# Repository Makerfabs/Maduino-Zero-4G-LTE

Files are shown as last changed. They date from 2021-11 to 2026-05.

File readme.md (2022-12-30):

# Maduino Zero 4G LTE

```c++
/*
Version:		V1.1
Author:			Vincent
Create Date:	2021/11/5
Note:
	2022/12/30	V1.1:	Change Wiki link.
*/
```
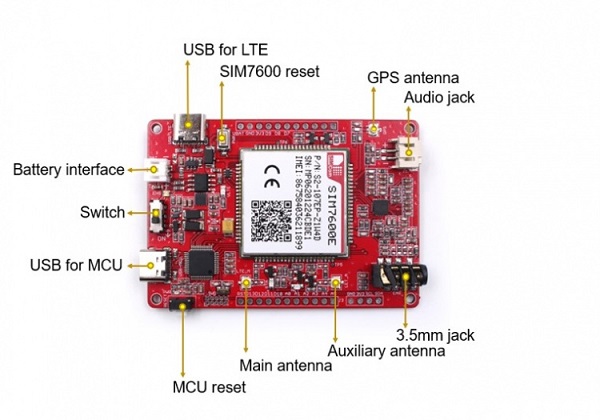
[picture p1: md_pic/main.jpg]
main


[toc]

# Makerfabs

[Makerfabs home page](https://www.makerfabs.com/)

[Makerfabs Wiki](https://wiki.makerfabs.com/)

# Maduino Zero 4G LTE
## Intruduce

Product Link ：[Maduino Zero 4G LTE(SIM7600X)](https://www.makerfabs.com/maduino-zero-4g-lte-sim7600.html) 

Wiki Link : [Maduino Zero 4G LTE](http://wiki.makerfabs.com/Maduino_Zero_4G_LTE.html) 

Maduino Zero 4G LTE integrated two types of the 4G LTE CAT4 module SIM7600A-H or SIM7600E-H, SIM7600A-H/SIM7600E-H is a complete multi-band LTE-FDD/LTE-TDD/HSPA+/UMTS/EDGE/GPRS/GSM module solution in LCC type which supports LTE CAT4 up to 150Mbps for downlink and 50Mbps for uplink data transfer, much faster and popular than 2G/3G.

## Module Type

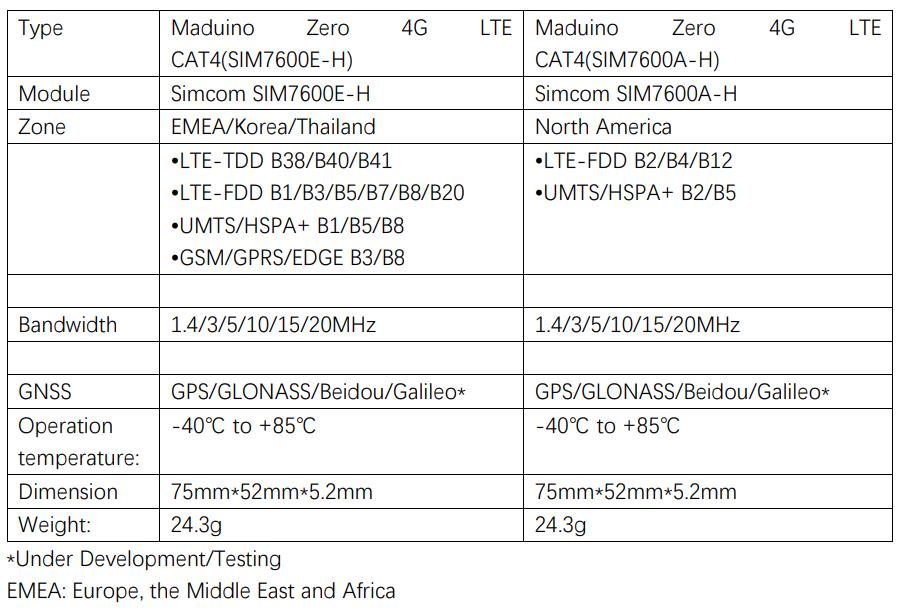
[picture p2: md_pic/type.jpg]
type


## Feature

- Supports dial-up, phone, SMS, TCP, UDP, DTMF, HTTP, FTP, and so on
- Dual USB Type C port
- Control Via AT Commands
- Board USB supply voltage range: 4.8~5.5V, 5.0V Typical
- Board Battery supply voltage range: 3.4~4.2V, 3.7V Typical
- 3GPP E-UTRA Release 11
- Onboard charger, up to 1A charge current
- Overcharge protection(OCP), 4.3V
- Over-discharge protection(ODP), 2.5V
- Power Manager, the board can be supplied by USB or battery.
- IPEX Antenna, GSM/UMTS/LTE main antenna. UMTS/LTE auxiliary antenna. GNSS antenna
- SMS support
- Audio support
- On boarder controller: ATSAMD21G18A
- Audio chip: NAU8810
- Level Shifter: TXS0108E

### Front:

front

### Back:
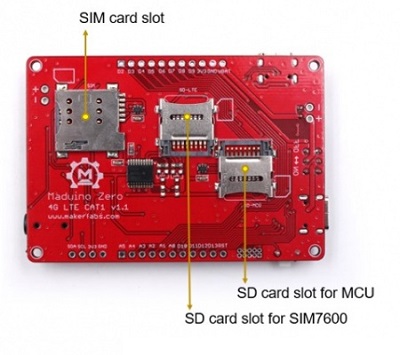
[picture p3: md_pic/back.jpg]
back


### Frequency bands

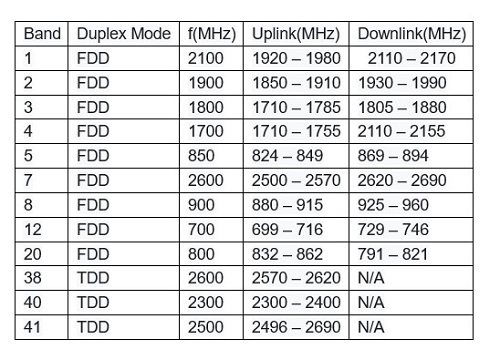
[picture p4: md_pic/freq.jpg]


### Transfer Speed

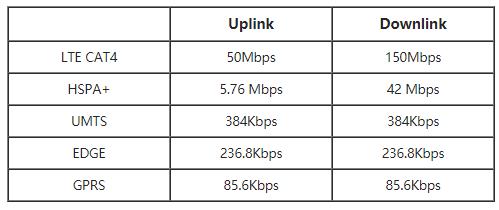
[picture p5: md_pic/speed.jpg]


# Usage （Arduino）

## Equipment list

- Maduino Zero 4G (With GPS antenna and two 4G-GSM antennas)
- SIM card 

*Ensure that SIM7600 requirements are met and that the system can communicate with local carriers. We used China Mobile's 4G card for testing.*

## Compiler Options

**If you have any questions，such as how to install the development board, how to download the code, how to install the library. Please refer to :[Makerfabs_FAQ](https://github.com/Makerfabs/Makerfabs_FAQ)**

- Connect all antennas
- Insert a SIM card
- Connect **USB for MCU** to PC

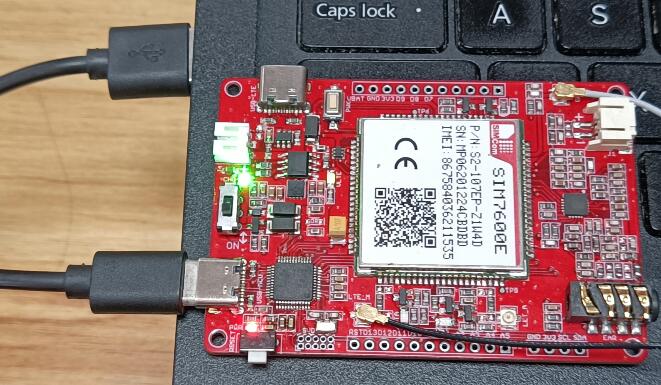
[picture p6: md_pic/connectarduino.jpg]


- Upload codes, select "Arduino Zero" and "Native USB"

## Example List

### AT_command_demo

Input AT commands via serial monitor to learn how to use 4G module. This version is modify for SIM7600.

If define MODE_1A, when "1A" or "1A" is entered, 0x1A is sent to the module.

When sending SNS information, you need to send 0x1A to end the input.

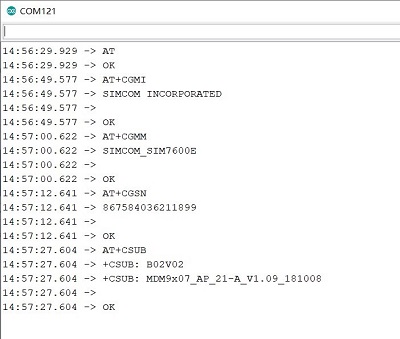
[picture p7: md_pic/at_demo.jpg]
at_demo


### 4G_HTTP_DHT11_V1.0

Air temperature and humidity information detected by the DHT11 module is sent to ThingSpeak using a cellular network.

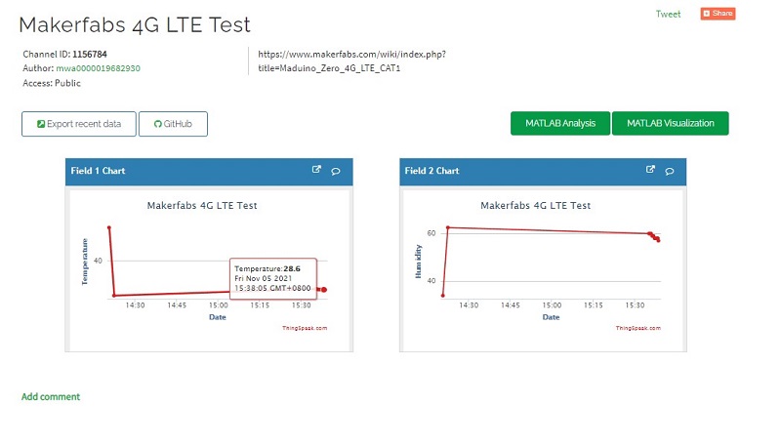
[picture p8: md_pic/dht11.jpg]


## AT Command Explain

###  AT commands test

Refer to the official AT manual of SIM7600 for detailed return values.

```c++
    AT+CGMI    // Request manufacturer identification
    AT+CGMM    // Request model identification
    AT+CGSN    // Request product serial number identification
    AT+CSUB    // Request the module version and chip
    AT+CPIN?     // Request the state of the SIM card
    AT+CICCID    // Read ICCID from SIM card
    AT+CNUM      // Request the subscriber number
    AT+CNMP?     // Preferred mode selection
    AT+COPS?     // Check the current network operator
```

### Get the GNSS location

GPS signal acquisition speed depends on signal strength, please wait patiently in an open place.

```c++
    AT+CGPS=1      // Start GPS session 
    AT+CGPSINFO    // Get GPS fixed position information
    AT+CGPS=0      // Stop GPS session
```

### Send and receive SMS

Please consult the operator for the phone number of the SMS center. The number "+8613800755500" in Shenzhen was used in the test. 

```c++
    AT+CSCA="XXXXXX"       // Set the SMS service centre address
    AT+CMGF=1              // Select SMS message format
    AT+CMGS="xxxxxx"       // Send message to "xxxxxx"(the receiver number).
```

"AT+CMGS" sets the phone number of the receiver and returns ' >' . Send desired content, such as "Send Massage Test!".After editing a short message, send it in hexadecimal format 1A Send a message.

*The Arduino IDE cannot send hexadecimal,  you can use other software. In the example code, entering 1A or 1A will send 0x1A to the module.*

# Usage （Raspberry Pi）

## Equipment list

- Maduino Zero 4G (With GPS antenna and two 4G-GSM antennas)
- SIM card 

*Ensure that SIM7600 requirements are met and that the system can communicate with local carriers. We used China Mobile's 4G card for testing.*

- Connect all antennas
- Insert a SIM card
- Connect **USB for MCU** to Raspberry Pi USB

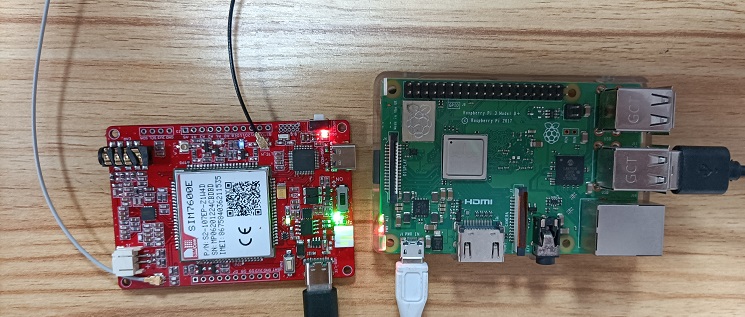
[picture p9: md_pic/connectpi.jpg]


## Used as a 4G network adapter

### Hardware Check

- Log in to the root account and perform all subsequent operations as the root account.

```shell
sudo su
```

- Install the Minicom serial port tool.

```shell
apt-get install minicom
```

- To view the serial port device, AT command serial port: "/dev/ttyUSB2"

```shell
ls /dev/ttyUSB*
```

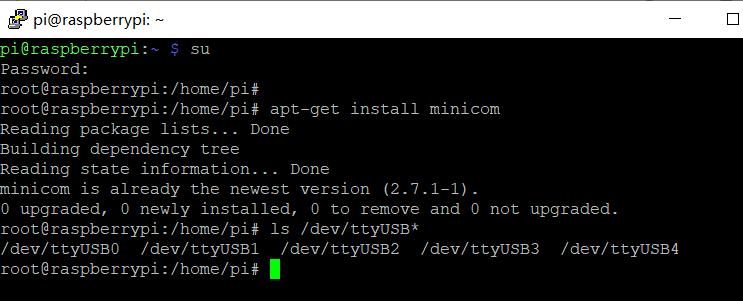
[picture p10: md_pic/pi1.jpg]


- Open the serial port with Minicom

```shell
minicom -D /dev/ttyUSB2
```

- Enter the AT command in minicom

```shell
# Forcibly set the Internet access to 4G
AT+CNMP=38
# Querying network Quality
AT+CSQ
# Query the network registry
AT+CREG?
# Querying Network Carrier Information
AT+COPS?
# Querying network band
AT+CPSI?
```

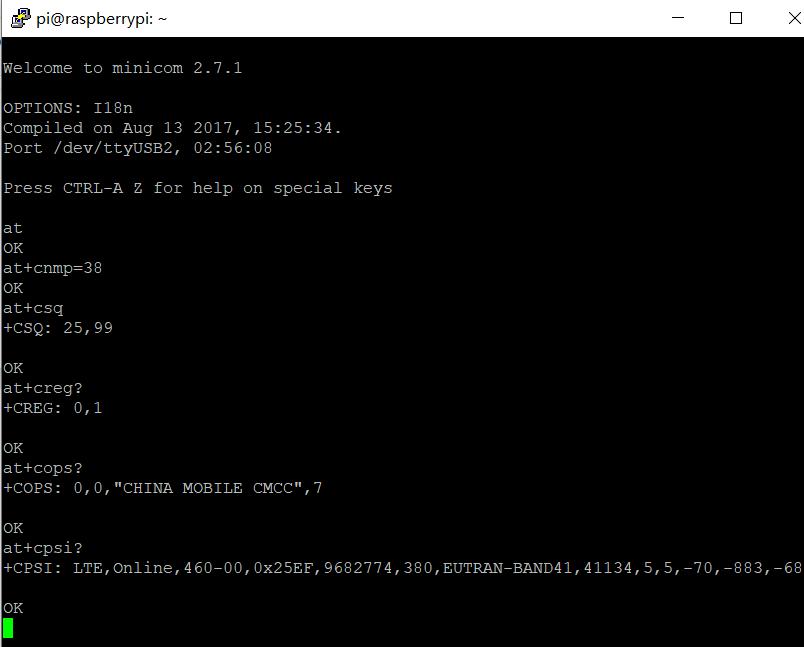
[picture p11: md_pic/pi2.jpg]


- \- Press Ctrl + A, then X to exit Minicom

At this point, the hardware and network connections between SIM7600CE and Raspberry Pi are normal. This case uses the 4G card of China Mobile. If you cannot use the other areas, please ask SIMCOM. 

### Driver Install

By default, Raspbian is installed with Qualcomm driver files for the wwan0 network port. For Raspberry Pi, you need to uninstall the driver first (otherwise it will conflict with the new driver), and then install the Simcom's driver for wwan0.

- Check system drivers

```shell
lsmod
```

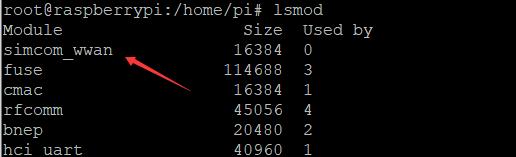
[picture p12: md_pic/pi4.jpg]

- Uninstalling an existing driver

```shell
rmmod qmi_wwan
```

- Install the raspberry PI kernel header file
```shell
apt install raspberrypi-kernel-headers
```
- Download the official driver program provided by SIMCOM
```shell
wget https://www.waveshare.net/w/upload/0/00/SIM7600_NDIS.7z
```
- Install the decompression tool and decompress it
```shell
apt-get install p7zip-full
7z x SIM7600_NDIS.7z -r -o ./SIM7600_NDIS
```
- Go to the driver folder and compile

```shell
cd SIM7600_NDIS
make clean
make
ls
```

- Install the driver module file

```shell
insmod simcom_wwan.ko
```

- Check whether the installation is successful
```shell
lsmod
```



### Assign IP addresses

- In this case, the wwan0 network port is displayed

```shell
ifconfig -a
```
- However, no IP address is assigned to the network port. To assign an IP address, enable the network port first

```shell
ifconfig wwan0 up
```
- Then, through Minicom, enter the AT command to start dialing

```shell
minicom -D /dev/ttyUSB2
AT$QCRMCALL=1,1
```
- Finally, exit Minicom and assign IP

```shell
apt-get install udhcpc
udhcpc -i wwan0
```
- Run the Ping command to check whether the network adapter is connected

```shell
ping -I wwan0 www.baidu.com
```

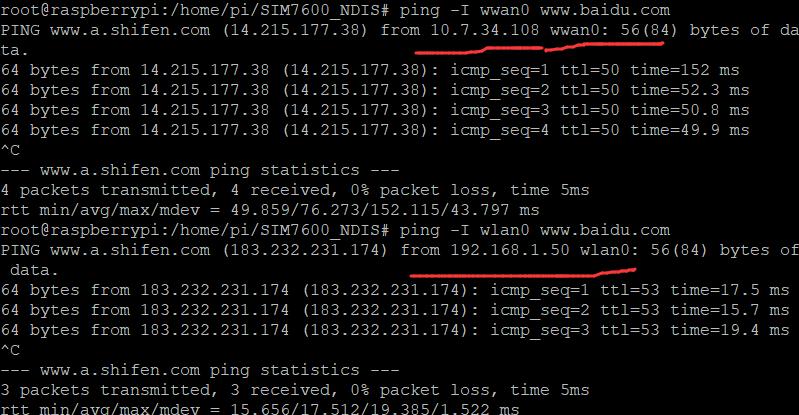
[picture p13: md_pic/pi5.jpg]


# Usage （Windows）

- Connect one end of USB cable to USB interface of PC and the other end to USB_LTE interface of Maduino Zero 4G LTE.

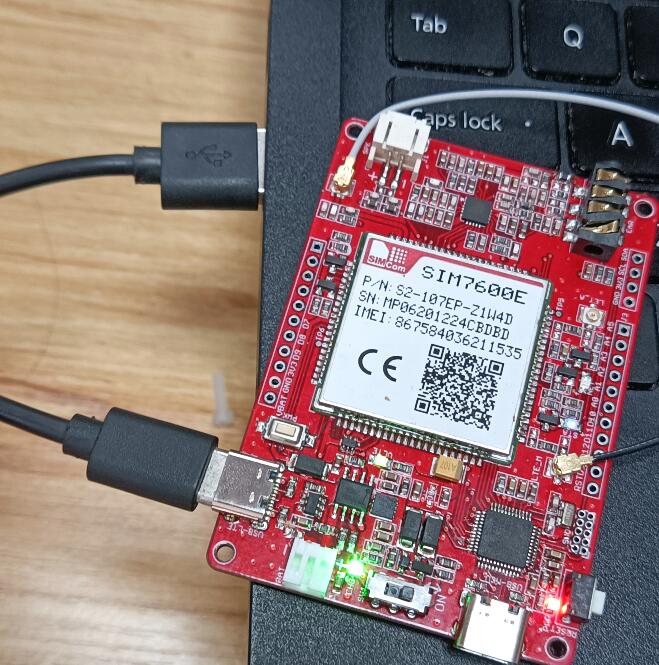
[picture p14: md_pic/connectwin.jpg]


- Open the device manager and you can see these COM ports.



- If the COM port is identified in the figure above, but an exclamation mark appears, it indicates that the driver is not installed.
- Driver is in "Maduino-Zero-4G-LTE\win_driver\SIM7600X-Driver.7z"
- Open Device Manager - > Other equipment - >“SimTech,Incorporated”- >  Update the driver - > Browse my computer to find driver files - > Select a path for saving the driver file based on the system- >The installation is complete.

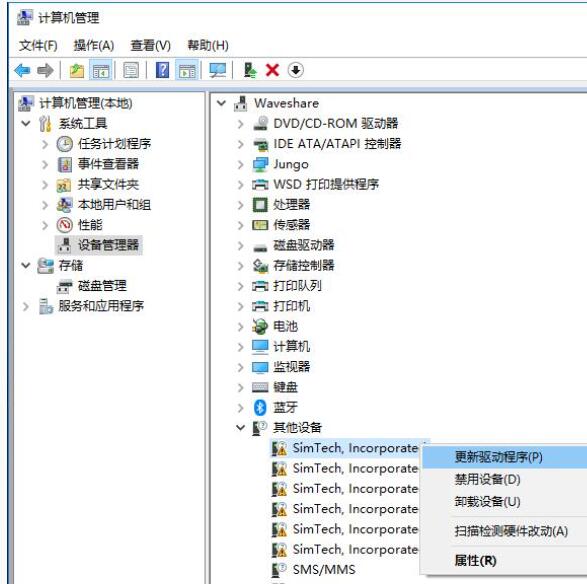
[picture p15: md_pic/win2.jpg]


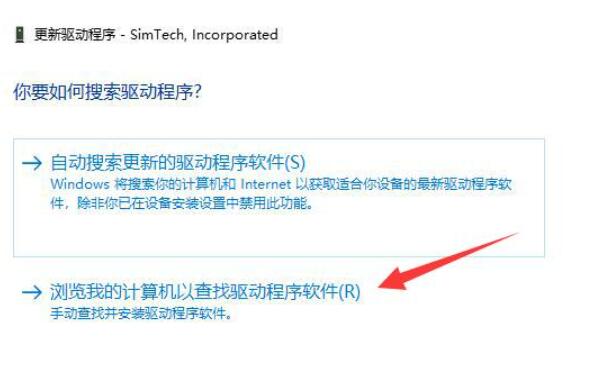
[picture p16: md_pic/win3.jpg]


- Install the driver for each exclamation point
- The network icon will then appear as a cellular network.

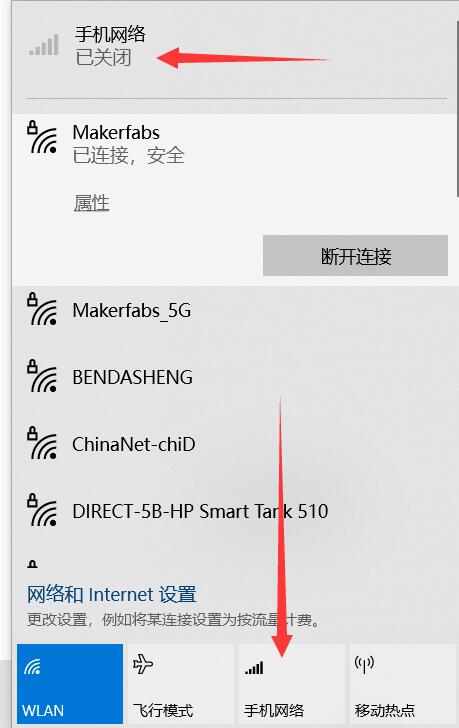
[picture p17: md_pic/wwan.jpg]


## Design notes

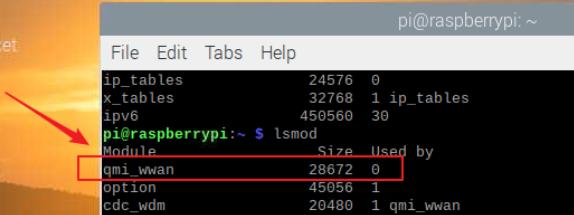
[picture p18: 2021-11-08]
md_pic/pi3.jpg

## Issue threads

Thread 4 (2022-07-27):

How to connect another serial device to board

keithfraley, 2022-07-27:
My understanding is that this board has two serial ports, one for serialUSB and one for serial1 used to communicate to the Modem.

I have another external serial device that I need to connect to the board.  Can you tell me how best to do this, specifically what digital port is configured to recieve data from a serial device via UART?

Thanks

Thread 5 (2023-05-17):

Is there a way to hard reset the board (No device found on COM5)

norcino, 2023-05-17:
When I try to upload a sketch (any, even empty), Arduino IDE gets stuck in Uploading....

Sometimes, but generally resetting the board with the button I get the expected.

"No device found on COM5"
"Failed upload: uploading error: exit status 1"

Is there anything I can do? I barely used the board to try commands and started writing a sketch.

norcino, 2023-07-22:
Plug the device and turn it on.
Touch the press the MCU reset button twice (quicly).
Wait a few seconds and when the device will be ready in Arduino, proceed with the upload.

Closed 2023-07-22.

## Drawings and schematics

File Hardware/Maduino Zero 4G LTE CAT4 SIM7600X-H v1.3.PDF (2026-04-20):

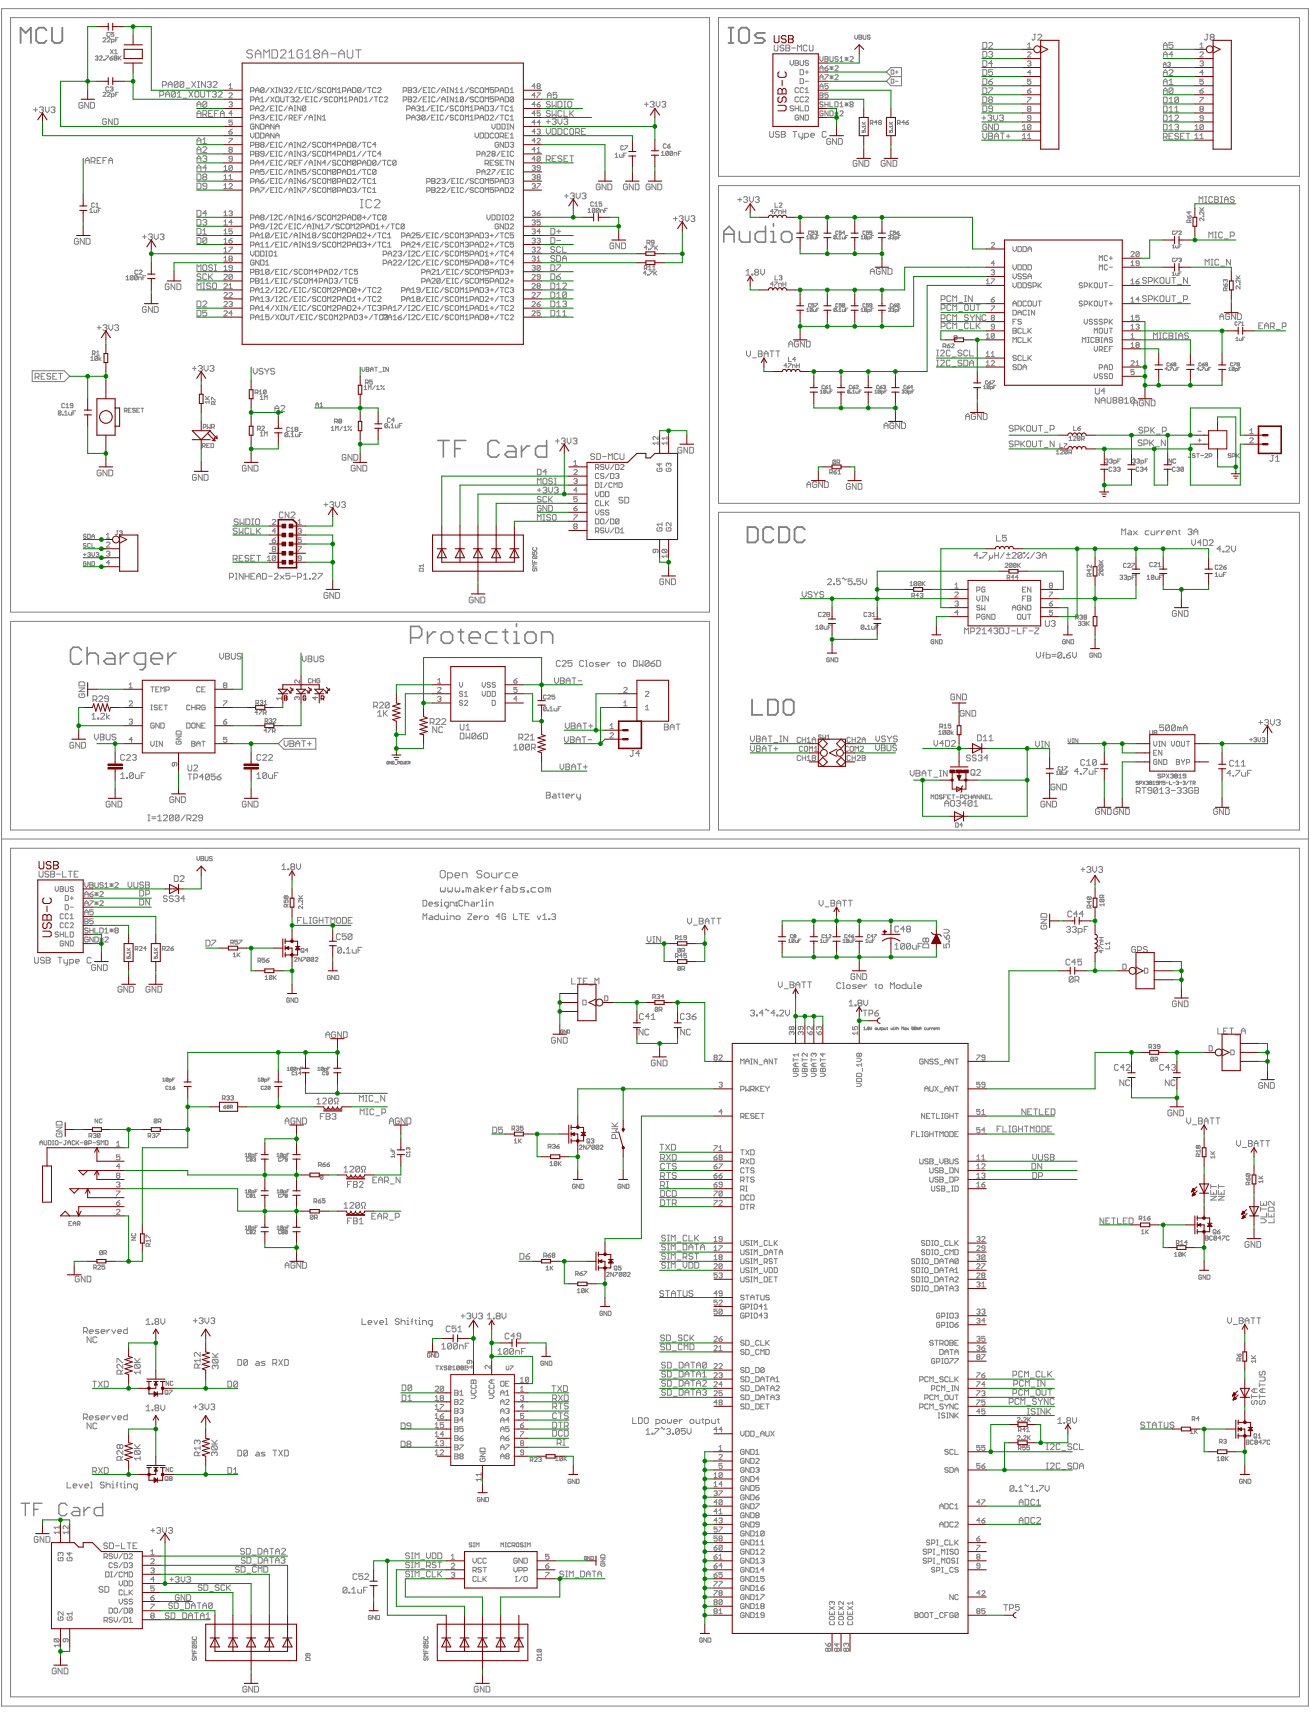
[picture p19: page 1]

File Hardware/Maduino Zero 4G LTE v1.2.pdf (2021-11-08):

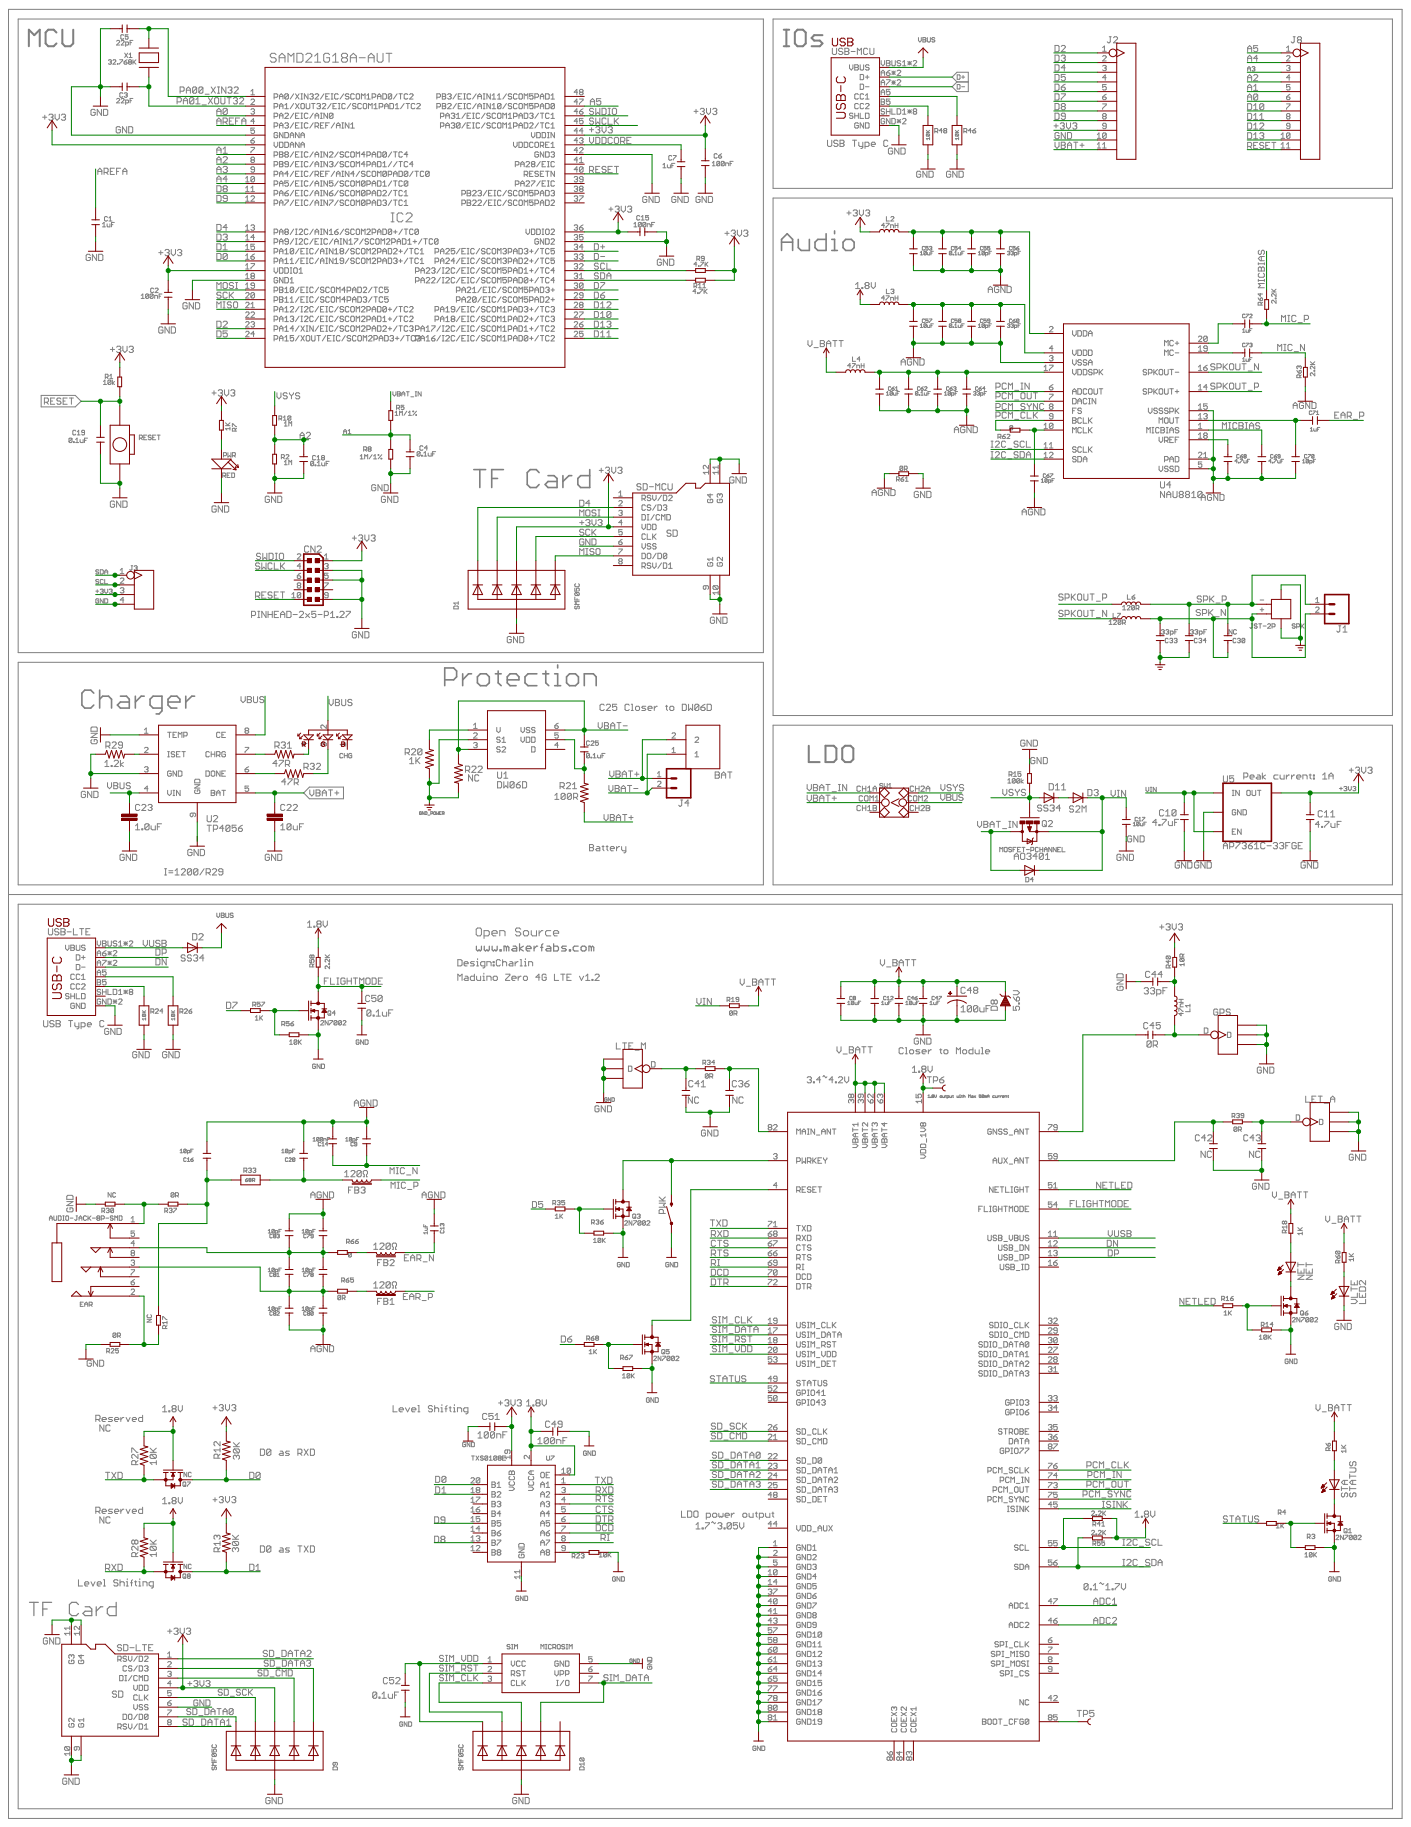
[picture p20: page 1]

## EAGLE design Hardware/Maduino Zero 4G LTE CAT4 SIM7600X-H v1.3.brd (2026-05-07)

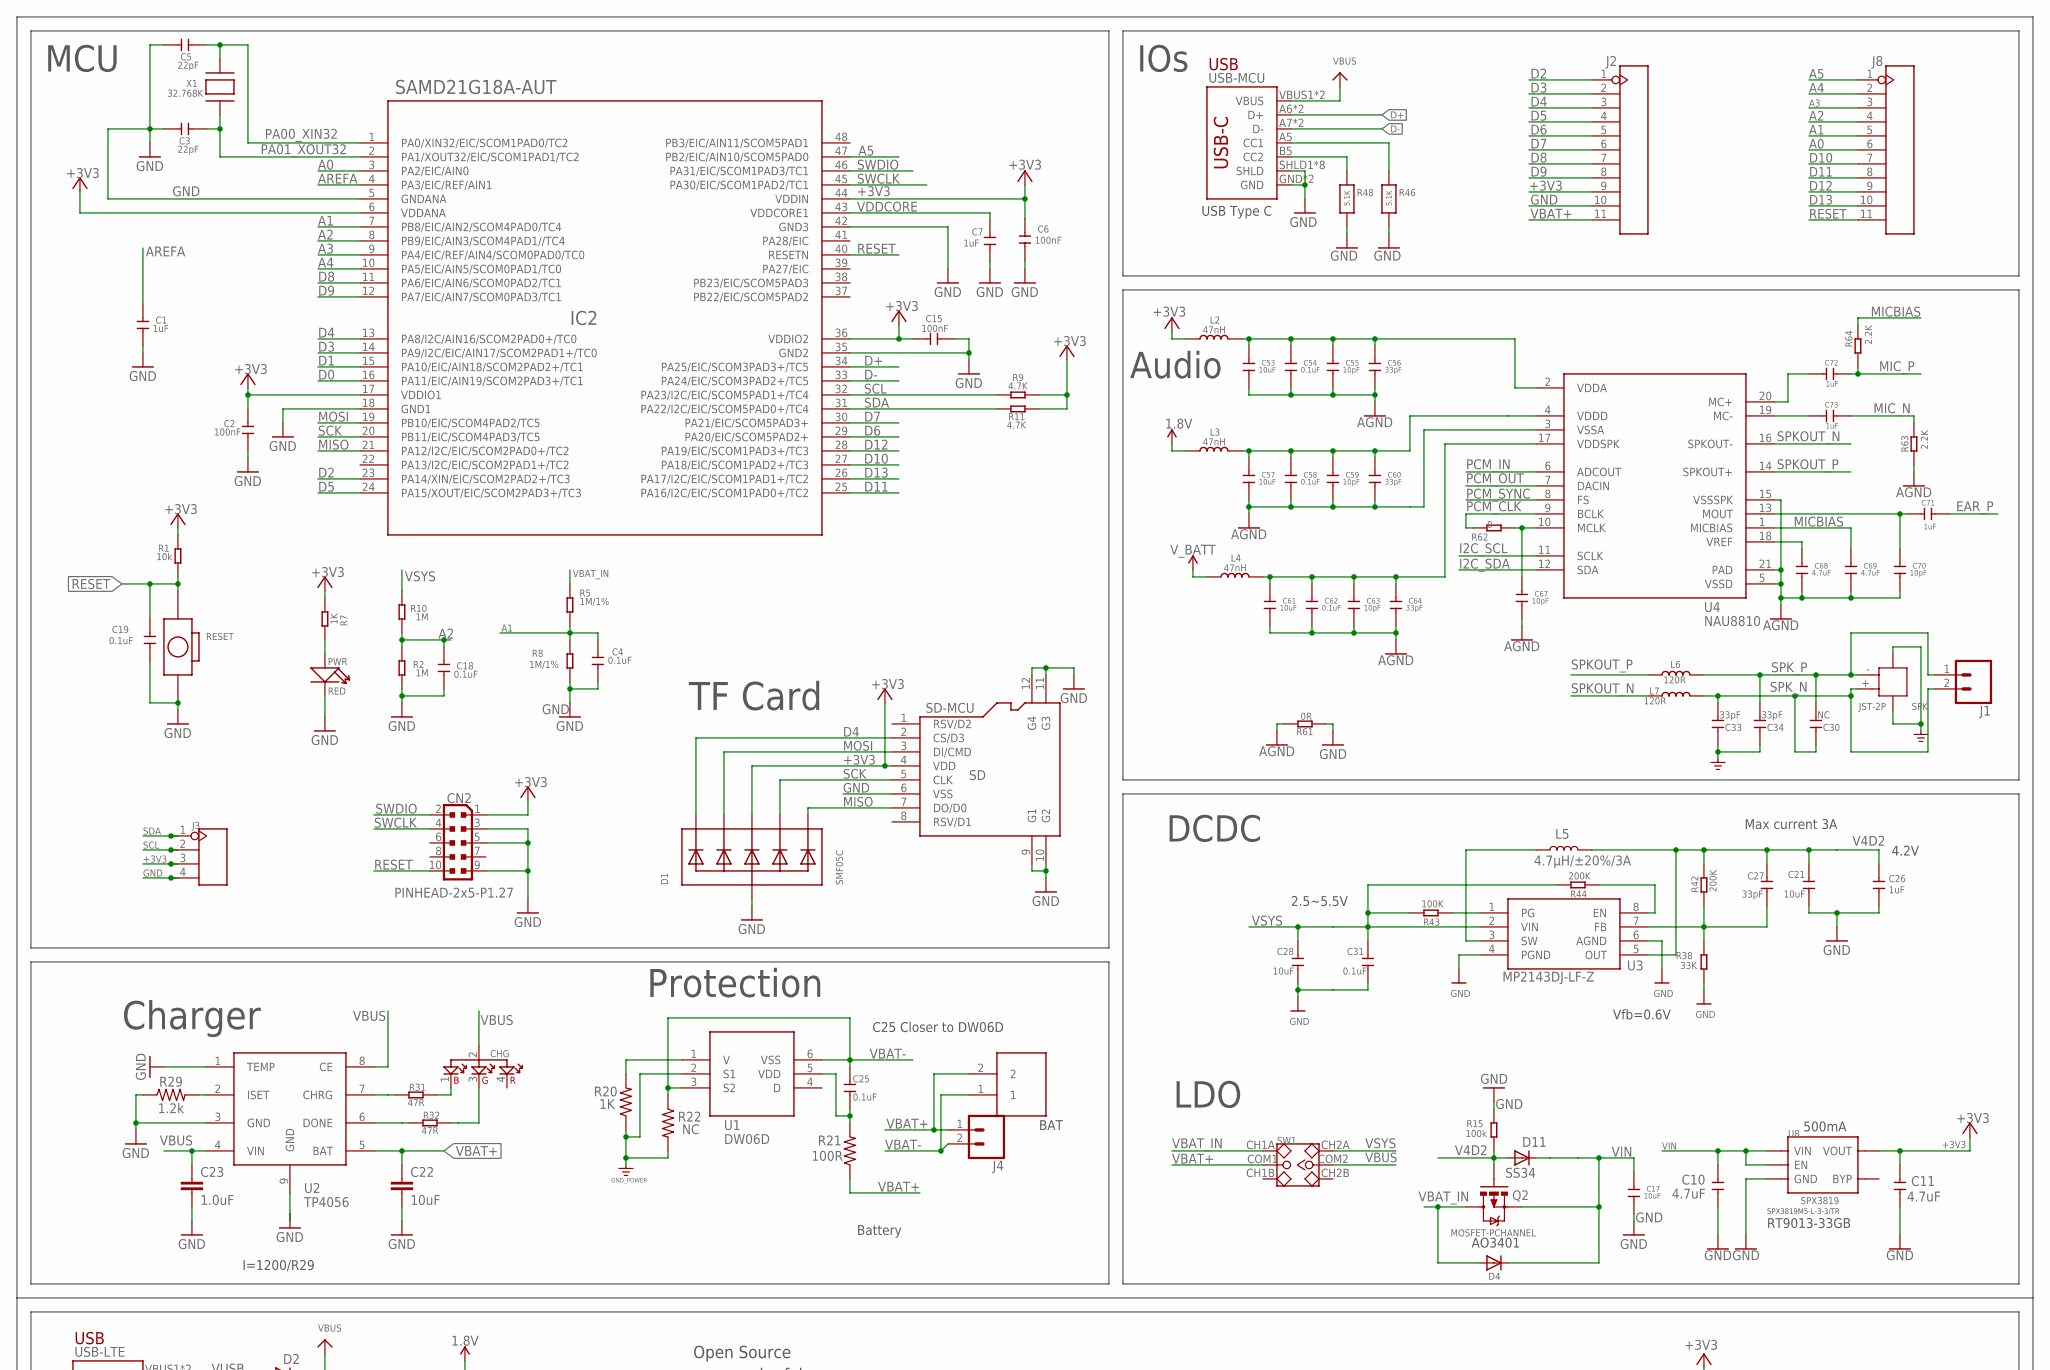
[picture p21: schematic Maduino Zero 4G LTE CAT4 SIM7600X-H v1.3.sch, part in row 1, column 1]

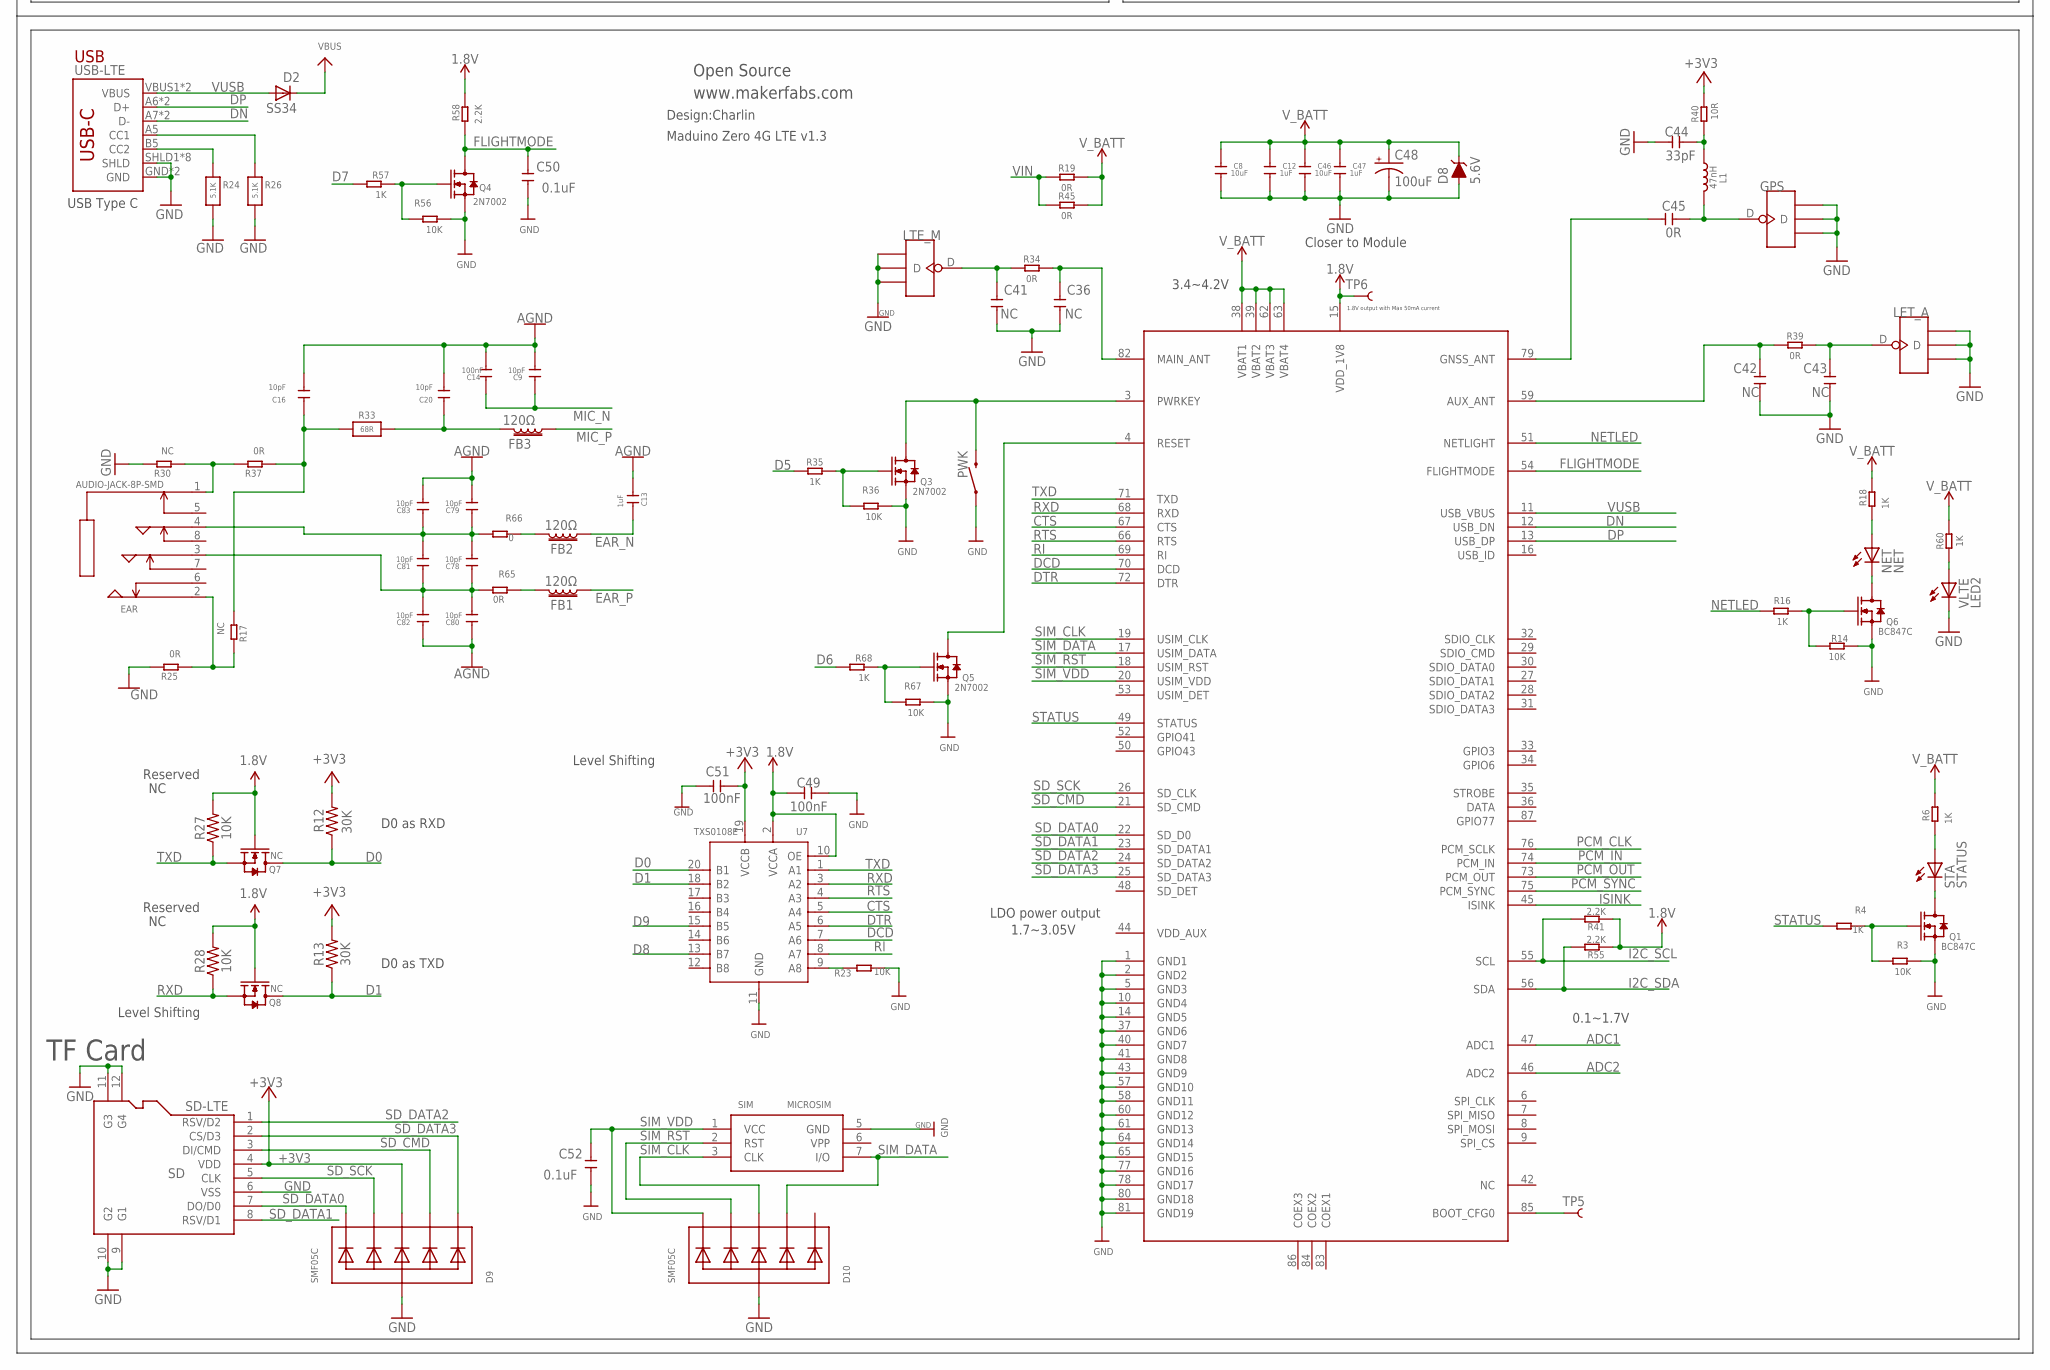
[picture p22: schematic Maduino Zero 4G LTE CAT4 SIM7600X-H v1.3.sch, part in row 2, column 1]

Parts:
BAT: PH2.0-2P-90-DIP
C1, C7, C12, C13, C26, C47, C71, C72, C73: 1uF; 0603
C2, C6, C14, C15, C49, C51: 100nF; 0603
C3, C5: 22pF; 0603
C4, C18, C19, C25, C31, C50, C52, C54, C58, C62: 0.1uF; 0603
C8, C17, C21, C22, C28, C46, C53, C57, C61: 10uF; 0603
C9, C16, C20, C55, C59, C63, C67, C70, C78, C79, C80, C81, C82, C83: 10pF; 0603
C10, C11, C68, C69: 4.7uF; 0603
C23: 1.0uF; 0603
C27, C44, C56, C60, C64: 33pF; 0603
C30: NC; C0603
C33, C34: 33pF; C0603
C36, C41, C42, C43: NC; 0603
C45: 0R; 0603
C48: 100uF; EIA3528
CHG: E6C0606RGBC3UDA; SMD4-160L160W
CN2: PINHEAD-2x5-P1.27; PINHEAD_2X05_127
D1, D9, D10: SMF05C; SOT363
D2, D11: SS34; DO-214AC
D4: DIODESOD-323F; SOD-323F
D8: 5.6V; SOD-323
EAR: AUDIO-JACK-8P-SMD; AUDIO8P-SMD-3.5-14.5X6.1X4.0MM
FB1, FB2, FB3: 120Ω; 0603
GPS: ANTENNA-U-FL; 4P-U-FL
IC2: SAMD21G18A-AUT; TQFP48-7X7
J1, J4: CONN_02LOCK; 1X02_LOCK
J2, J8: HEADER-11P-2.54; 11P-2.54
J3: HEADER-4P-60/35MILROUND; 4P-65/35ROUND
L1, L2, L3, L4: 47nH; L0603
L5: 4.7µH/±20%/3A; SRN6045
L6, L7: 120R; L0603
LET_A: ANTENNA-U-FL; 4P-U-FL
LTE_M: ANTENNA-U-FL; 4P-U-FL
NET: NET; CHIP-LED0805
PWK: MOMENTARY-SWITCH-SPST-SMD-6.0X3.5MM; TACTILE_SWITCH_SMD_6.0X3.5MM
PWR: RED; LED-0603
Q1, Q6: BC847C; SOT23
Q2: MOSFET-PCHANNEL; SOT23-3
Q3, Q4, Q5: 2N7002; SOT23
Q7, Q8: NC; SOT23
R1: 10k; R0603
R2, R10: 1M; R0603
R3, R14, R23, R36, R56, R67: 10K; R0603
R4, R6, R7, R16, R18, R35, R57, R60, R68: 1K; R0603
R5, R8: 1M/1%; R0603
R9, R11: 4.7K; R0603
R12, R13: 30K; 0603
R15: 100k; R0603
R17, R30: NC; R0603
R19, R25, R34, R37, R39, R45, R61, R65: 0R; R0603
R20: 1K; 0603
R21: 100R; 0603
R22: NC; 0603
R24, R26, R46, R48: 5.1K; 0603-NO
R27, R28: 10K; 0603
R29: 1.2k; 0603
R31, R32: 47R; R0603
R33: 68R; 0603-NO
R38: 33K; R0603
R40: 10R; R0603
R41, R55, R58, R63, R64: 2.2K; R0603
R42, R44: 200K; R0603
R43: 100K; R0603
R62, R66: 0; R0603
RESET: BOTTON-2P-90D; 2P-7.62X3.56-90D
SD-LTE: SD; 8P-SMD
SD-MCU: SD; 8P-SMD
SIM: MICROSIM
SPK: JST-2P; HW2-SMD-2.0-90D
STA: STATUS; CHIP-LED0805
SW1: SWITCH-2CH-6P; 6P-2CH-2.54-7.6X3.0
TP5, TP6: TEST-POINT3; PAD.03X.03
U1: DW06D; SOT-23-6
U2: TP4056; SOP8-1.27P
U3: MP2143DJ-LF-Z; TSOT23-8
U4: NAU8810; QFN21-50P-400L400W
U6: SIM7600; SMD87-100P-3000L300W
U7: TXS0108E; TSSOP20-0.65-6.5X4.4MM
U8: SPX3819; SOT23-5
USB-LTE: USB_C5; USB-C-16P-5
USB-MCU: USB_C5; USB-C-16P-5
VLTE: LED2; CHIP-LED0805
X1: 32.768K; XTAL3215

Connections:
1.8V: C49.2, L3.1, Q7.1 (G), Q8.1 (G), R27.2, R28.2, R41.1, R55.1, R58.2, TP6.P$1, U6.15 (VDD_1V8), U7.2 (VCCA), U7.10 (OE)
+3V3: C2.2, C6.1, C11.2, C15.1, C51.1, CN2.1, D1.4 (C3), D9.4 (C3), IC2.6 (VDDANA), IC2.17 (VDDIO1), IC2.36 (VDDIO2), IC2.44 (VDDIN), J2.9, J3.3, L2.1, R1.2, R7.1, R9.2, R11.2, R12.2, R13.2, R40.2, SD-LTE.4 (VDD), SD-MCU.4 (VDD), U7.19 (VCCB), U8.5 (VOUT)
A0: IC2.3 (PA2/EIC/AIN0), J8.6
A1: C4.1, IC2.7 (PB8/EIC/AIN2/SCOM4PAD0/TC4), J8.5, R5.1, R8.2
A2: C18.1, IC2.8 (PB9/EIC/AIN3/SCOM4PAD1//TC4), J8.4, R2.2, R10.1
A3: IC2.9 (PA4/EIC/REF/AIN4/SCOM0PAD0/TC0), J8.3
A4: IC2.10 (PA5/EIC/AIN5/SCOM0PAD1/TC0), J8.2
A5: IC2.47 (PB2/EIC/AIN10/SCOM5PAD0), J8.1
ADC1: U6.47 (ADC1)
ADC2: U6.46 (ADC2)
AGND: C9.1, C13.2, C14.1, C16.1, C20.1, C53.1, C54.1, C55.1, C56.1, C57.1, C58.1, C59.1, C60.1, C61.1, C62.1, C63.1, C64.1, C67.1, C68.1, C69.1, C70.1, C79.1, C80.2, C82.2, C83.1, R61.2, R63.1, U4.3 (VSSA), U4.5 (VSSD), U4.15 (VSSSPK), U4.21 (PAD)
AREFA: C1.1, IC2.4 (PA3/EIC/REF/AIN1)
CTS: U6.67 (CTS), U7.5 (A4)
D0: IC2.16 (PA11/EIC/AIN19/SCOM2PAD3+/TC1), Q7.3 (D), R12.1, U7.20 (B1)
D1: IC2.15 (PA10/EIC/AIN18/SCOM2PAD2+/TC1), Q8.3 (D), R13.1, U7.18 (B2)
D2: IC2.23 (PA14/XIN/EIC/SCOM2PAD2+/TC3), J2.1
D3: IC2.14 (PA9/I2C/EIC/AIN17/SCOM2PAD1+/TC0), J2.2
D4: D1.1 (C1), IC2.13 (PA8/I2C/AIN16/SCOM2PAD0+/TC0), J2.3, SD-MCU.2 (CS/D3)
D5: IC2.24 (PA15/XOUT/EIC/SCOM2PAD3+/TC3), J2.4, R35.2
D6: IC2.29 (PA20/EIC/SCOM5PAD2+), J2.5, R68.2
D7: IC2.30 (PA21/EIC/SCOM5PAD3+), J2.6, R57.2
D8: IC2.11 (PA6/EIC/AIN6/SCOM0PAD2/TC1), J2.7, U7.13 (B7)
D9: IC2.12 (PA7/EIC/AIN7/SCOM0PAD3/TC1), J2.8, U7.15 (B5)
D10: IC2.27 (PA18/EIC/SCOM1PAD2+/TC3), J8.7
D11: IC2.25 (PA16/I2C/EIC/SCOM1PAD0+/TC2), J8.8
D12: IC2.28 (PA19/EIC/SCOM1PAD3+/TC3), J8.9
D13: IC2.26 (PA17/I2C/EIC/SCOM1PAD1+/TC2), J8.10
D+: IC2.34 (PA25/EIC/SCOM3PAD3+/TC5), USB-MCU.A6 (D+), USB-MCU.B6 (D+)
D-: IC2.33 (PA24/EIC/SCOM3PAD2+/TC5), USB-MCU.A7 (D-), USB-MCU.B7 (D-)
DCD: U6.70 (DCD), U7.7 (A6)
DN: U6.12 (USB_DN), USB-LTE.A7 (D-), USB-LTE.B7 (D-)
DONE: R32.2, U2.6 (DONE)
DP: U6.13 (USB_DP), USB-LTE.A6 (D+), USB-LTE.B6 (D+)
DTR: U6.72 (DTR), U7.6 (A5)
EAR_N: C13.1, FB2.1
EAR_P: C71.1, FB1.1
FLIGHTMODE: C50.2, Q4.3 (D), R58.1, U6.54 (FLIGHTMODE)
GND: C1.2, C2.1, C3.2, C4.2, C5.2, C6.2, C7.2, C8.1, C10.1, C11.1, C12.1, C15.2, C17.1, C18.2, C19.1, C21.1, C22.2, C23.2, C26.1, C28.1, C31.1, C33.2, C34.2, C36.1, C41.1, C42.1, C43.1, C44.2, C46.1, C47.1, C48.C (-), C49.1, C50.1, C51.2, C52.1, CN2.3, CN2.5, CN2.9, D1.2 (A), D8.A, D9.2 (A), D10.2 (A), GPS.GND1, GPS.GND2, GPS.GND3, IC2.5 (GNDANA), IC2.18 (GND1), IC2.35 (GND2), IC2.42 (GND3), J2.10, J3.4, LET_A.GND1, LET_A.GND2, LET_A.GND3, LTE_M.GND1, LTE_M.GND2, LTE_M.GND3, PWK.1, PWR.-, Q1.2 (S), Q3.2 (S), Q4.2 (S), Q5.2 (S), Q6.2 (S), R2.1, R3.1, R8.1, R14.1, R15.2, R20.1, R22.2, R23.1, R24.2, R25.2, R26.2, R29.1, R30.2, R36.1, R38.1, R46.2, R48.2, R56.1, R61.1, R67.1, RESET.P$2 (2), SD-LTE.6 (VSS), SD-LTE.9 (G1), SD-LTE.10 (G2), SD-LTE.11 (G3), SD-LTE.12 (G4), SD-MCU.6 (VSS), SD-MCU.9 (G1), SD-MCU.10 (G2), SD-MCU.11 (G3), SD-MCU.12 (G4), SIM.5 (GND), SPK.3, SPK.4, U1.2 (S1), U2.1 (TEMP), U2.3 (GND), U2.9 (GND), U3.4 (PGND), U3.6 (AGND), U6.1 (GND1), U6.2 (GND2), U6.5 (GND3), U6.10 (GND4), U6.14 (GND5), U6.37 (GND6), U6.40 (GND7), U6.41 (GND8), U6.43 (GND9), U6.57 (GND10), U6.58 (GND11), U6.60 (GND12), U6.61 (GND13), U6.64 (GND14), U6.65 (GND15), U6.77 (GND16), U6.78 (GND17), U6.80 (GND18), U6.81 (GND19), U7.11 (GND), U8.2 (GND), USB-LTE.GND, USB-LTE.GND2 (GND), USB-LTE.SHLD1 (SHLD), USB-LTE.SHLD2 (SHLD), USB-LTE.SHLD3 (SHLD), USB-LTE.SHLD4 (SHLD), USB-LTE.SHLD5 (SHLD), USB-LTE.SHLD6 (SHLD), USB-LTE.SHLD7 (SHLD), USB-LTE.SHLD8 (SHLD), USB-MCU.GND, USB-MCU.GND2 (GND), USB-MCU.SHLD1 (SHLD), USB-MCU.SHLD2 (SHLD), USB-MCU.SHLD3 (SHLD), USB-MCU.SHLD4 (SHLD), USB-MCU.SHLD5 (SHLD), USB-MCU.SHLD6 (SHLD), USB-MCU.SHLD7 (SHLD), USB-MCU.SHLD8 (SHLD), VLTE.C
I2C_SCL: R41.2, U4.11 (SCLK), U6.55 (SCL)
I2C_SDA: R55.2, U4.12 (SDA), U6.56 (SDA)
ISET: R29.2, U2.2 (ISET)
ISINK: U6.45 (ISINK)
MICBIAS: C69.2, R64.2, U4.1 (MICBIAS)
MIC_N: C9.2, C14.2, C73.1, R63.2
MIC_P: C72.1, FB3.1, R64.1
MISO: D1.6 (C5), IC2.21 (PA12/I2C/EIC/SCOM2PAD0+/TC2), SD-MCU.7 (DO/D0)
MOSI: D1.3 (C2), IC2.19 (PB10/EIC/SCOM4PAD2/TC5), SD-MCU.3 (DI/CMD)
unnamed: Q1.1 (G), R3.2, R4.1
unnamed: R6.1, STA.A
unnamed: PWR.+, R7.2
unnamed: Q1.3 (D), STA.C
unnamed: Q6.1 (G), R14.2, R16.1
unnamed: NET.A, R18.1
unnamed: NET.C, Q6.3 (D)
unnamed: TP5.P$1, U6.85 (BOOT_CFG0)
unnamed: C25.2, R21.2, U1.5 (VDD)
unnamed: R20.2, U1.1 (V)
unnamed: CHG.3, R32.1
unnamed: R31.2, U2.7 (CHRG)
unnamed: CHG.1, R31.1
unnamed: C16.2, R17.1, R33.1, R37.1
unnamed: C20.2, FB3.2, R33.2
unnamed: EAR.2, R17.2, R25.1
unnamed: R26.1, USB-LTE.A5 (CC1)
unnamed: R24.1, USB-LTE.B5 (CC2)
unnamed: EAR.1, R30.1, R37.2
unnamed: C78.1, C79.2, C81.1, C83.2, EAR.4, R66.1
unnamed: L5.1, U3.3 (SW)
unnamed: C27.1, R38.2, R42.1, U3.7 (FB)
unnamed: R23.2, U7.9 (A8)
unnamed: R46.1, USB-MCU.A5 (CC1)
unnamed: R48.1, USB-MCU.B5 (CC2)
unnamed: R43.1, U3.1 (PG)
unnamed: R44.1, U3.8 (EN)
unnamed: C36.2, R34.1, U6.82 (MAIN_ANT)
unnamed: C41.2, LTE_M.D, R34.2
unnamed: PWK.2, Q3.3 (D), U6.3 (PWRKEY)
unnamed: Q3.1 (G), R35.1, R36.2
unnamed: R60.1, VLTE.A
unnamed: C53.2, C54.2, C55.2, C56.2, L2.2, U4.2 (VDDA)
unnamed: C70.2, C71.2, U4.13 (MOUT)
unnamed: C61.2, C62.2, C63.2, C64.2, L4.2, U4.17 (VDDSPK)
unnamed: C68.2, U4.18 (VREF)
unnamed: C57.2, C58.2, C59.2, C60.2, L3.2, U4.4 (VDDD)
unnamed: C73.2, U4.19 (MC-)
unnamed: C67.2, R62.1, U4.10 (MCLK)
unnamed: C72.2, U4.20 (MC+)
unnamed: FB1.2, R65.2
unnamed: FB2.2, R66.2
unnamed: C78.2, C80.1, C81.2, C82.1, EAR.3, R65.1
unnamed: Q5.3 (D), U6.4 (RESET)
unnamed: Q5.1 (G), R67.2, R68.1
unnamed: C43.2, LET_A.D, R39.2
unnamed: C44.1, L1.1, R40.1
unnamed: C42.2, R39.1, U6.59 (AUX_ANT)
unnamed: C45.2, U6.79 (GNSS_ANT)
unnamed: C45.1, GPS.D, L1.2
unnamed: Q4.1 (G), R56.2, R57.1
NETLED: R16.2, U6.51 (NETLIGHT)
PA00_XIN32: C5.1, IC2.1 (PA0/XIN32/EIC/SCOM1PAD0/TC2), X1.P$2
PA01_XOUT32: C3.1, IC2.2 (PA1/XOUT32/EIC/SCOM1PAD1/TC2), X1.P$1
PCM_CLK: R62.2, U4.9 (BCLK), U6.76 (PCM_SCLK)
PCM_IN: U4.6 (ADCOUT), U6.74 (PCM_IN)
PCM_OUT: U4.7 (DACIN), U6.73 (PCM_OUT)
PCM_SYNC: U4.8 (FS), U6.75 (PCM_SYNC)
RESET: C19.2, CN2.10, IC2.40 (RESETN), J8.11, R1.1, RESET.P$1 (1)
RI: U6.69 (RI), U7.8 (A7)
RTS: U6.66 (RTS), U7.4 (A3)
RXD: Q8.2 (S), R28.1, U6.68 (RXD), U7.3 (A2)
SCK: D1.5 (C4), IC2.20 (PB11/EIC/SCOM4PAD3/TC5), SD-MCU.5 (CLK)
SCL: IC2.32 (PA23/I2C/EIC/SCOM5PAD1+/TC4), J3.2, R9.1
SDA: IC2.31 (PA22/I2C/EIC/SCOM5PAD0+/TC4), J3.1, R11.1
SD_CMD: D9.3 (C2), SD-LTE.3 (DI/CMD), U6.21 (SD_CMD)
SD_DATA0: D9.6 (C5), SD-LTE.7 (DO/D0), U6.22 (SD_D0)
SD_DATA1: SD-LTE.8 (RSV/D1), U6.23 (SD_DATA1)
SD_DATA2: SD-LTE.1 (RSV/D2), U6.24 (SD_DATA2)
SD_DATA3: D9.1 (C1), SD-LTE.2 (CS/D3), U6.25 (SD_DATA3)
SD_SCK: D9.5 (C4), SD-LTE.5 (CLK), U6.26 (SD_CLK)
SIM_CLK: D10.4 (C3), SIM.3 (CLK), U6.19 (USIM_CLK)
SIM_DATA: D10.3 (C2), SIM.7 (I/O), U6.17 (USIM_DATA)
SIM_RST: D10.5 (C4), SIM.2 (RST), U6.18 (USIM_RST)
SIM_VDD: C52.2, D10.6 (C5), SIM.1 (VCC), U6.20 (USIM_VDD)
SPKOUT_N: L7.1, U4.16 (SPKOUT-)
SPKOUT_P: L6.1, U4.14 (SPKOUT+)
SPK_N: C30.2, C33.1, J1.2, L7.2, SPK.+ (1)
SPK_P: C30.1, C34.1, J1.1, L6.2, SPK.- (2)
STATUS: R4.2, U6.49 (STATUS)
SWCLK: CN2.4, IC2.45 (PA30/EIC/SCOM1PAD2/TC1)
SWDIO: CN2.2, IC2.46 (PA31/EIC/SCOM1PAD3/TC1)
TXD: Q7.2 (S), R27.1, U6.71 (TXD), U7.1 (A1)
V4D2: C21.2, C26.2, C27.2, D11.A, L5.2, Q2.1 (G), R15.1, R42.2, U3.5 (OUT)
VBAT+: BAT.2, C22.1, J2.11, J4.1, R21.1, SW1.COM1, U2.5 (BAT)
VBAT-: BAT.1, C25.1, J4.2, R22.1, U1.3 (S2), U1.6 (VSS)
VBAT_IN: D4.A, Q2.3 (D), R5.2, SW1.CH1A
VBUS: C23.1, CHG.2, D2.C, SW1.COM2, U2.4 (VIN), U2.8 (CE), USB-MCU.VBUS1 (VBUS), USB-MCU.VBUS2 (VBUS)
VDDCORE: C7.1, IC2.43 (VDDCORE1)
VIN: C10.2, C17.2, D4.C, D11.C, Q2.2 (S), R19.2, R45.2, U8.1 (VIN), U8.3 (EN)
VSYS: C28.2, C31.2, R10.2, R43.2, R44.2, SW1.CH2A, U3.2 (VIN)
VUSB: D2.A, U6.11 (USB_VBUS), USB-LTE.VBUS1 (VBUS), USB-LTE.VBUS2 (VBUS)
V_BATT: C8.2, C12.2, C46.2, C47.2, C48.A (+), D8.C, L4.1, R6.2, R18.2, R19.1, R45.1, R60.2, U6.38 (VBAT1), U6.39 (VBAT2), U6.62 (VBAT3), U6.63 (VBAT4)

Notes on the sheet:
500mA
www.makerfabs.com
MCU
IOs
LDO
Design:Charlin
Open Source
AO3401
Maduino Zero 4G LTE v1.3
Closer to Module
1.8V output with Max 50mA current
LDO power output
3.4~4.2V
0.1~1.7V
1.7~3.05V
Battery
C25 Closer to DW06D
Protection
BAT
I=1200/R29
Level Shifting
Reserved
USB
USB Type C
TF Card
Audio
Charger
D0 as RXD
D0 as TXD
SPX3819M5-L-3-3/TR
RT9013-33GB
4.2V
Max current 3A
Vfb=0.6V
2.5~5.5V
DCDC

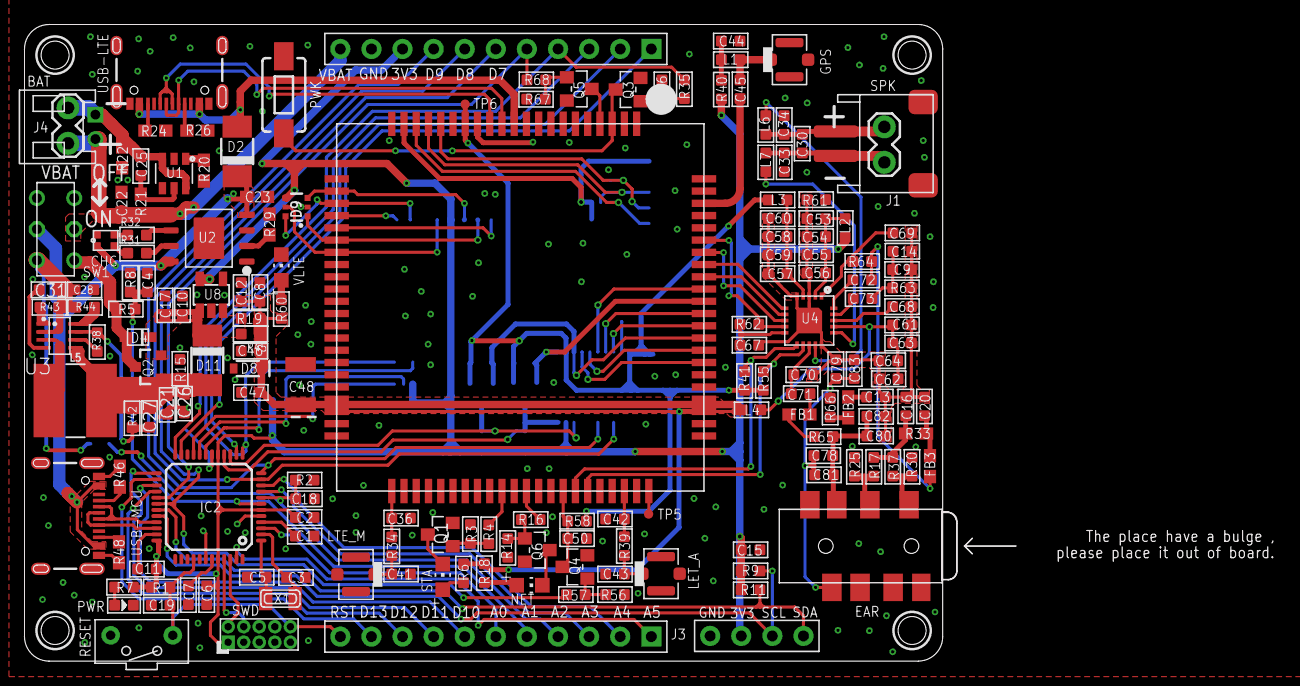
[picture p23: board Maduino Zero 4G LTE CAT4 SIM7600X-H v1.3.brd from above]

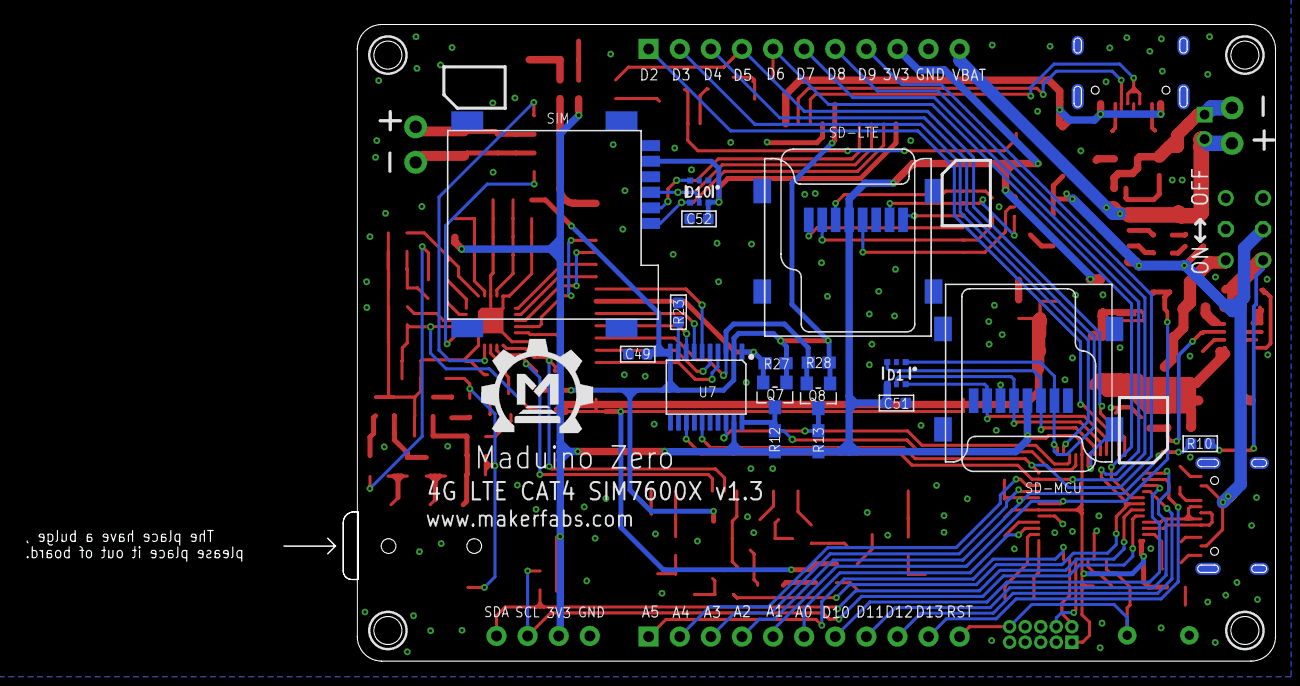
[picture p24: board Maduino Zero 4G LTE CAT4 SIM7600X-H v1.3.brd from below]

Board: 2 copper layers, 81.0 x 52.0 mm, 191 parts (18 on the bottom side), 137 nets.

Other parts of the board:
U$1: MAKERFABS_0.3

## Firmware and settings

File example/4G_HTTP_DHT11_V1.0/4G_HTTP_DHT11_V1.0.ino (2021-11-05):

#include <stdio.h>
#include <string.h>
#include <DHT.h>

//Description: input AT commands via serial monitor to learn how to use A9/A9G module
//version:v1.0
//Author:Charlin
//web: http://www.makerfabs.com
//

//Change the API key to yours
String Apikey = "2ZOQP7ZGJ9OVGU6X";

#define DEBUG true

#define LTE_RESET_PIN 6

#define LTE_PWRKEY_PIN 5

#define LTE_FLIGHT_PIN 7


#define Sensor_PIN 3  //D3-DHT11

DHT  dht(Sensor_PIN,DHT11);



void setup()
{
    SerialUSB.begin(115200);
    //while (!SerialUSB)
    {
      ; // wait for Arduino serial Monitor port to connect
    }
    Serial1.begin(115200);
  
    //Serial1.begin(UART_BAUD, SERIAL_8N1, MODEM_RXD, MODEM_TXD);
  
    pinMode(LTE_RESET_PIN, OUTPUT);
    digitalWrite(LTE_RESET_PIN, LOW);
  
    pinMode(LTE_PWRKEY_PIN, OUTPUT);
    digitalWrite(LTE_RESET_PIN, LOW);
    delay(100);
    digitalWrite(LTE_PWRKEY_PIN, HIGH);
    delay(2000);
    digitalWrite(LTE_PWRKEY_PIN, LOW);
    
    pinMode(LTE_FLIGHT_PIN, OUTPUT);
    digitalWrite(LTE_FLIGHT_PIN, LOW);//Normal Mode
    
    delay(5000);

    
    /*ModuleState = moduleStateCheck();
    if (ModuleState == false) //if it's off, turn on it.
    {
        digitalWrite(PWR_KEY, LOW);
        delay(3000);
        digitalWrite(PWR_KEY, HIGH);
        delay(10000);
        SerialUSB.println("Now turnning the SIM7600 on.");
    }*/
    

    //sendData("AT+CCID", 3000, DEBUG);
    //sendData("AT+CREG?", 3000, DEBUG);
    //sendData("AT+CGATT=1", 1000, DEBUG);
    //sendData("AT+CGACT=1,1", 1000, DEBUG);
    //sendData("AT+CGDCONT=1,\"IP\",\"CMNET\"", 1000, DEBUG);

    //sendData("AT+CIPSTART=\"TCP\",\"www.mirocast.com\",80", 2000, DEBUG);
    SerialUSB.println("4G HTTP Test Begin!");

    dht.begin();
    delay(1000);
}

void loop()
{
    //--------Get temperature and humidity-------------
    float h = dht.readHumidity();
    float t = dht.readTemperature();

    //-----------HTTP---------------------
    String http_str = "AT+HTTPPARA=\"URL\",\"https://api.thingspeak.com/update?api_key=" + Apikey + "&field1=" + (String)t + "&field2=" + (String)h + "\"\r\n";
    SerialUSB.println(http_str);

    sendData("AT+HTTPINIT\r\n", 2000, DEBUG);
    sendData(http_str, 2000, DEBUG);
    sendData("AT+HTTPACTION=0\r\n", 3000, DEBUG);
    sendData("AT+HTTPTERM\r\n", 3000, DEBUG);

    delay(5000);   
    
    /*
    while (Serial1.available() > 0)
    {
        SerialUSB.write(Serial1.read());
        yield();
    }
    while (SerialUSB.available() > 0)
    {
        int c = -1;
        c = SerialUSB.read();
        if (c != '\n' && c != '\r')
        {
            from_usb += (char)c;
        }
        else
        {
            if (!from_usb.equals(""))
            {
                //SerialUSB.println(from_usb);
                sendData(from_usb, 0, DEBUG);
                from_usb = "";
            }
        }

        // Serial1.write(SerialUSB.read());
        // yield();
    }
    */
}

bool moduleStateCheck()
{
    int i = 0;
    bool moduleState = false;
    for (i = 0; i < 5; i++)
    {
        String msg = String("");
        msg = sendData("AT", 1000, DEBUG);
        if (msg.indexOf("OK") >= 0)
        {
            SerialUSB.println("SIM7600 Module had turned on.");
            moduleState = true;
            return moduleState;
        }
        delay(1000);
    }
    return moduleState;
}

String sendData(String command, const int timeout, boolean debug)
{
  String response = "";
  Serial1.println(command);
  
  long int time = millis();
  while ( (time + timeout) > millis())
  {
    while (Serial1.available())
    {
      char c = Serial1.read();
      response += c;
    }
  }
  if (debug)
  {
    SerialUSB.print(response);
  }
  return response;
}

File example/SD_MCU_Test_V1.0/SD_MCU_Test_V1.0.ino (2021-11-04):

#include<stdio.h>
#include<string.h>

#define DEBUG true

//include the SD library:
#include <SPI.h>
#include <SD.h>

//www.makerfabs.com
//Test SD card
//version:v1.0
//author:Charlin
//date:2021/10/13

#define LTE_RESET_PIN 6

#define LTE_PWRKEY_PIN 5

#define LTE_FLIGHT_PIN 7

// set up variables using the SD utility library functions:
Sd2Card card;
SdVolume volume;
SdFile root;

// change this to match your SD shield or module;
// Maduino zero 4G LTE: pin 4
const int PIN_SD_SELECT = 4;

#define UART_BAUD           115200

#define MODEM_RXD          0
#define MODEM_TXD          1

File myFile;

void setup()
{

  SerialUSB.begin(115200);
  //while (!SerialUSB)
  {
    ; // wait for Arduino serial Monitor port to connect
  }
  Serial1.begin(115200);

  //Serial1.begin(UART_BAUD, SERIAL_8N1, MODEM_RXD, MODEM_TXD);

  pinMode(LTE_RESET_PIN, OUTPUT);
  digitalWrite(LTE_RESET_PIN, LOW);

  pinMode(LTE_PWRKEY_PIN, OUTPUT);
  digitalWrite(LTE_RESET_PIN, LOW);
  delay(100);
  digitalWrite(LTE_PWRKEY_PIN, HIGH);
  delay(2000);
  digitalWrite(LTE_PWRKEY_PIN, LOW);
  
  pinMode(LTE_FLIGHT_PIN, OUTPUT);
  digitalWrite(LTE_FLIGHT_PIN, LOW);//Normal Mode 
 // digitalWrite(LTE_FLIGHT_PIN, HIGH);//Flight Mode
  

  
  
  SerialUSB.println("Maduino Zero 4G _SD_Test Start!");
  
  SerialUSB.print("\nInitializing SD card...");
  if (!SD.begin(PIN_SD_SELECT)) {
    SerialUSB.println("initialization failed!");
    while (1);
  }
  SerialUSB.println("initialization done.");


  delay(1000);

  myFile = SD.open("test.txt", FILE_WRITE);

  // if the file opened okay, write to it:
  if (myFile) {
    SerialUSB.print("Writing to test.txt...");
    myFile.println("testing 1, 2, 3.");
    // close the file:
    myFile.close();
    SerialUSB.println("done.");
  } else {
    // if the file didn't open, print an error:
    SerialUSB.println("error opening test.txt");
  }

  // re-open the file for reading:
  myFile = SD.open("test.txt");
  if (myFile) {
    SerialUSB.println("test.txt:");

    // read from the file until there's nothing else in it:
    while (myFile.available()) {
      SerialUSB.write(myFile.read());
    }
    // close the file:
    myFile.close();
  } else {
    // if the file didn't open, print an error:
    SerialUSB.println("error opening test.txt");
  }
   
}

void loop()
{
  //SerialUSB.println("echo test!");
  while (Serial1.available() > 0) {
    SerialUSB.write(Serial1.read());
    yield();
  }
  while (SerialUSB.available() > 0) {
    Serial1.write(SerialUSB.read());
    yield();
  }
}


String sendData(String command, const int timeout, boolean debug)
{
  String response = "";
  Serial1.println(command);
  long int time = millis();
  while ( (time + timeout) > millis())
  {
    while (Serial1.available())
    {
      char c = Serial1.read();
      response += c;
    }
  }
  if (debug)
  {
    SerialUSB.print(response);
  }
  return response;
}

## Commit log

2021-11-04 Create hardware and AT command
    [Maduino Zero 4G LTE CAT1 v1.1.brd, Maduino Zero 4G LTE CAT1 v1.1.sch]
2021-11-05 Fix at command demo
    [AT_command_demo.ino]
2021-11-08 Add files via upload
    add hardware
    [Maduino Zero 4G LTE v1.2.brd, Maduino Zero 4G LTE v1.2.sch]
2021-11-09 Add Win Driver
2026-04-20 Updates the hardware
    [Maduino Zero 4G LTE CAT1 SIM7600X v1.3.brd, Maduino Zero 4G LTE CAT1 SIM7600X v1.3.sch]
2026-05-07 Update the file name
    [Maduino Zero 4G LTE CAT4 SIM7600X-H v1.3.brd, Maduino Zero 4G LTE CAT4 SIM7600X-H v1.3.sch]

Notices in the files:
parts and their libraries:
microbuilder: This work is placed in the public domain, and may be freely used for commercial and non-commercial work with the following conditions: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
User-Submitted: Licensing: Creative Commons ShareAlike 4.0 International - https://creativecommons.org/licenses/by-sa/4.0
